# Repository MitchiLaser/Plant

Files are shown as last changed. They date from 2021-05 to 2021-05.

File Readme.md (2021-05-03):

# automatic watering setup for a plant

This repository provides an electronic circuit board to water a plant. Is is driven by a microcontroller, an Attiny85, which gets the moldness of the soil in the pot from a sensor and powers a pump when it gets to dry.

In this repository you can find an electronic circuit board, designed in KiCad, as long as a firmware for the MCU and a 3d printable case. More documentation can be found on [my website](https://www.spice-space.de/inhalt/Pflanzenbewaesserung/index.html)

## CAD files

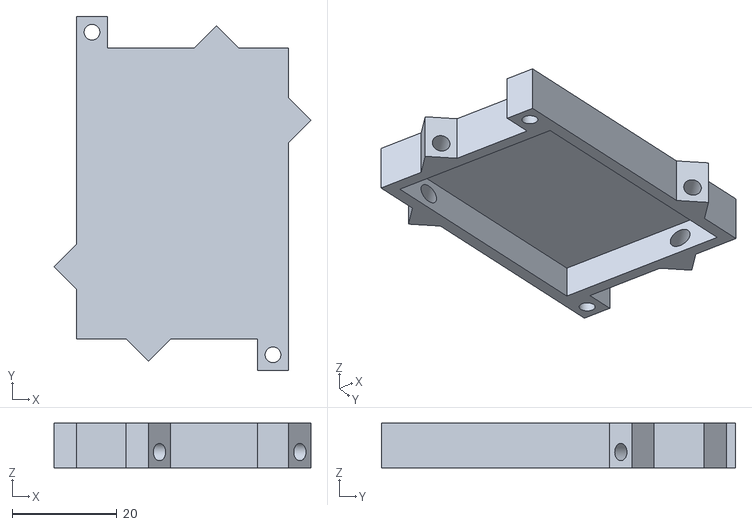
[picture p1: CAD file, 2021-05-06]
case/lid.stl
49.0 x 67.5 x 8.50

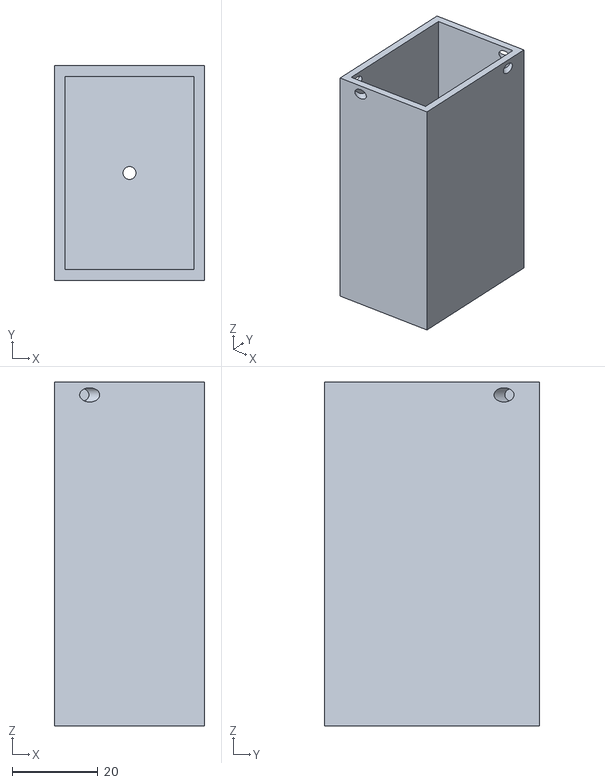
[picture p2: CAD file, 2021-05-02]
case/cage.stl
35.0 x 50.0 x 80.0

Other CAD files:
case/OldVersions/assembly.0005.iam
case/OldVersions/lid.0022.ipt
case/assembly.iam
case/cage.ipt
case/lid.ipt

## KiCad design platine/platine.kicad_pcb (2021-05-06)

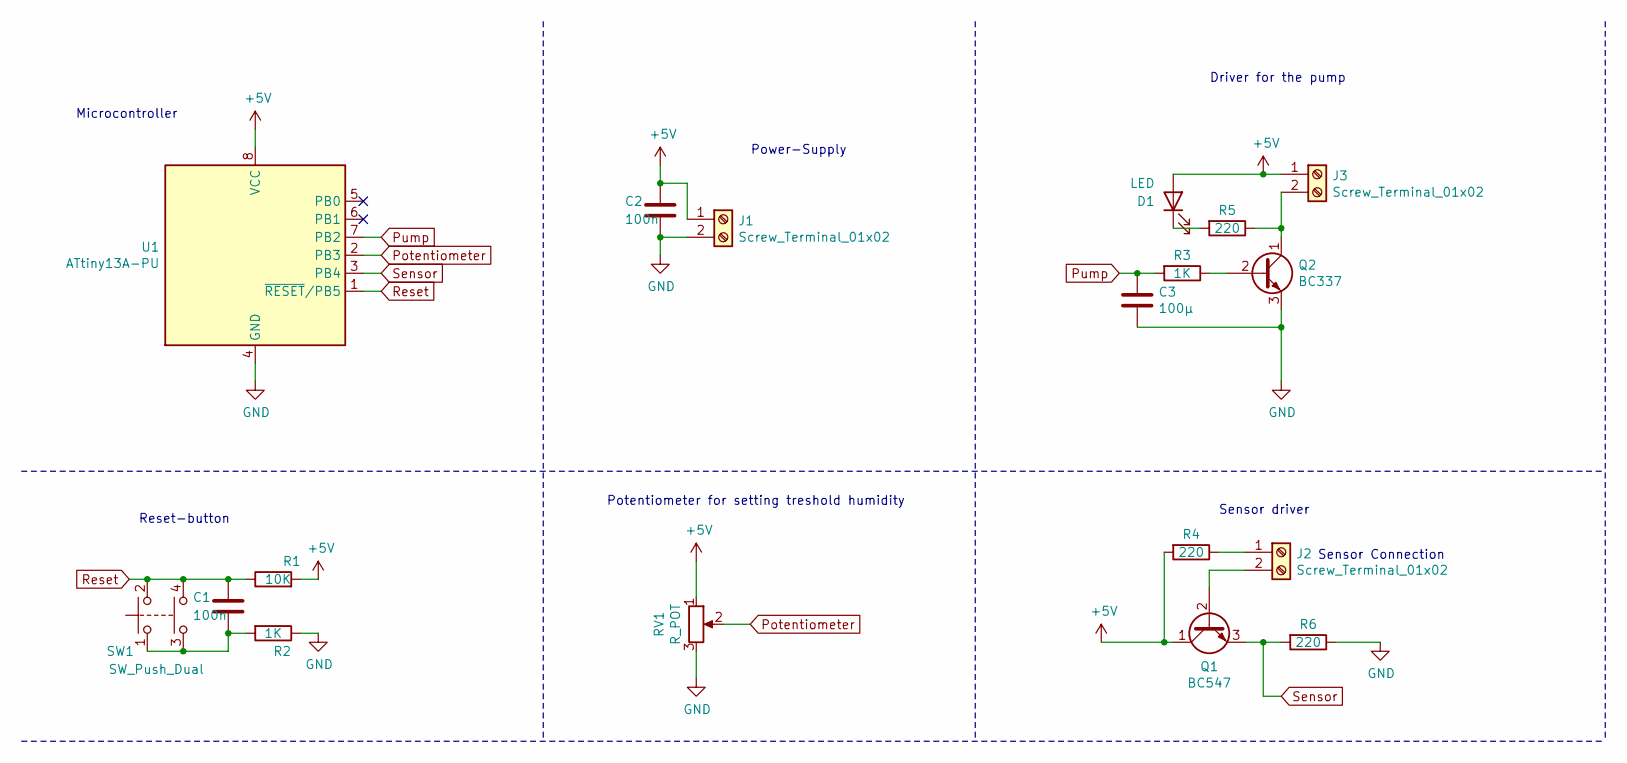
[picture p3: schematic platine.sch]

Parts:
C1, C2: 100n; C_Disc_D6.0mm_W2.5mm_P5.00mm
C3: 100µ; CP_Radial_D5.0mm_P2.50mm
D1: LED; LED_D5.0mm
J1, J2, J3: Screw_Terminal_01x02; TerminalBlock_Phoenix_MKDS-1,5-2-5.08_1x02_P5.08mm_Horizont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
Q1: BC547; TO-92_Inline
Q2: BC337; TO-92_Inline
R1: 10K; R_Axial_DIN0207_L6.3mm_D2.5mm_P7.62mm_Horizontal
R2, R3: 1K; R_Axial_DIN0207_L6.3mm_D2.5mm_P7.62mm_Horizontal
R4, R5, R6: 220; R_Axial_DIN0207_L6.3mm_D2.5mm_P7.62mm_Horizontal
RV1: R_POT; Potentiometer_Alps_RK163_Single_Horizontal
SW1: SW_Push_Dual; SW_TH_Tactile_Omron_B3F-10xx
U1: ATtiny13A-PU; DIP-8_W7.62mm

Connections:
+5V: C2.1, D1.2 (A), J1.1, J3.1, Q1.1 (C), R1.2, R4.2, RV1.1, U1.8 (VCC)
GND: C2.2, C3.2, J1.2, Q2.3 (E), R2.1, R6.1, RV1.3, U1.4 (GND)
unnamed: C1.2, R2.2, SW1.1, SW1.3
unnamed: D1.1 (K), R5.2
unnamed: J2.1, R4.1
unnamed: J2.2, Q1.2 (B)
unnamed: J3.2, Q2.1 (C), R5.1
unnamed: Q2.2 (B), R3.1
Potentiometer: RV1.2, U1.2 (PB3)
Pump: C3.1, R3.2, U1.7 (PB2)
Reset: C1.1, R1.1, SW1.2, SW1.4, U1.1 (~RESET~/PB5)
Sensor: Q1.3 (E), R6.2, U1.3 (PB4)

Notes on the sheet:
Microcontroller
Power-Supply
Driver for the pump
Reset-button
Potentiometer for setting treshold humidity
Sensor Connection
Sensor driver

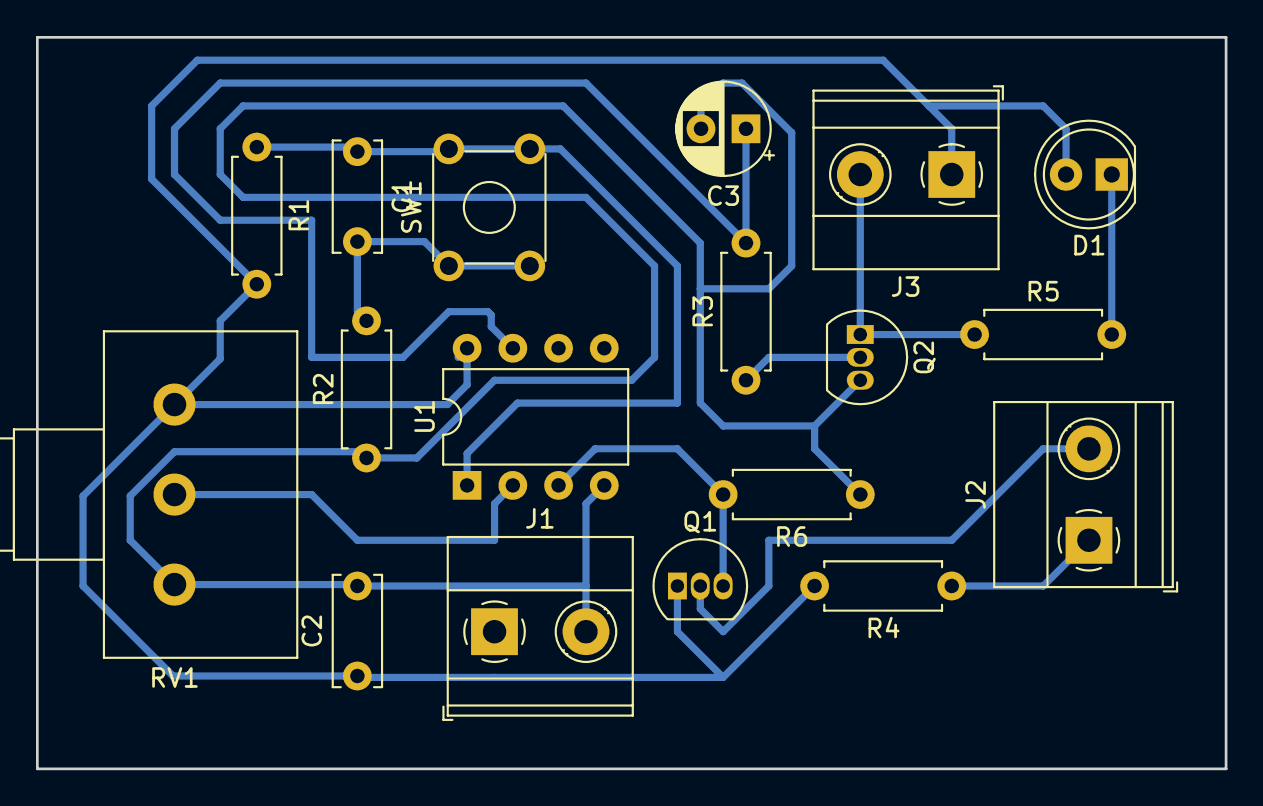
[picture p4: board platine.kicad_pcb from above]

Board: 2 copper layers, 66.0 x 40.6 mm, 18 parts (0 on the bottom side), 12 nets.

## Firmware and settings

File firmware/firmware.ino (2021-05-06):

// configuration
#define ADC_in A2 // pin connected to the analog moisture sensor
#define Pump_Out 2 // pin connected to the transistor, driving the pump
#define Pot_in A3 // the pin connected to the potentiometer

unsigned long last_Poll, wait;

void setup() {
  // drive pin connected to the moisture sensor and the potentiometer as input
  pinMode(ADC_in, INPUT);
  pinMode(Pot_in, INPUT);

  // drive pin connected to the transistor as output and close the transistor
  pinMode(Pump_Out, OUTPUT);
  digitalWrite(Pump_Out, HIGH);
  last_Poll = millis();

  wait = 1000; // wait 1000 milliseconds for every sensor check , equals 1 second
}

void loop() {

  if ( (millis() - wait) > last_Poll ) {
    last_Poll = millis();

    // get the value from the moisture sensor
    unsigned int Sensor_value = 0;
    for (unsigned int i = 0; i < 10; i++) {
      Sensor_value += analogRead(ADC_in);
    }
    Sensor_value /= 10;

    // get the value from the potentiometer
    unsigned int Pot_value = 0;
    for (unsigned int i = 0; i < 10; i++) {
      Pot_value += analogRead(Pot_in);
    }
    Pot_value /= 10;

    // if sensor value is smaller then potentiometer value then the earth is to dry -> water it
    if (Sensor_value < Pot_value) {
      digitalWrite(Pump_Out, HIGH);
    } else {
      digitalWrite(Pump_Out, LOW);
    }
  }
}

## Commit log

2021-04-29 Platine design: pump driver, power supply, reset-button, potentiometer
    [platine.kicad_pcb, platine.sch]
2021-05-01 Firmware timer-based and removed unnecessaries from scematics
    [platine.sch]
2021-05-01 scematics ready
    [platine.sch]
2021-05-01 pcb footprints assigned
    [platine.sch]
2021-05-01 PCB Design done
2021-05-01 small optimisations on PCB
    [platine.kicad_pcb]
2021-05-02 small PCB donr
2021-05-02 small PCB done
    [platine.kicad_pcb]
2021-05-02 corrected pin assignment in firmware
    [firmware.ino]
2021-05-02 corrected wrong pin assignment in firmware
    [firmware.ino]
2021-05-02 3d-printable case
    [assembly.iam, cage.ipt, cage.stl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]
2021-05-03 case: improved lid
    [assembly.0005.iam, assembly.iam, lid.0022.ipt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]
2021-05-06 Firmware: software-fix for hardware issue
    [firmware.ino]
2021-05-06 PCB: Added capacitor to smooth signal
    [platine.kicad_pcb, platine.sch]
